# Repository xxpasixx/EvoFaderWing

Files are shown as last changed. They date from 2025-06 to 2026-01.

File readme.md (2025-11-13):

# EvoFaderWing - [Wiki](https://github.com/stagehandshawn/EvoFaderWing/wiki)

<table width="100%">
  <tr>
    <td width="70%">
      <table width="100%">
        <tr>
          <td align="left">
            <strong>Author:</strong> ShawnR
          </td>
          <td align="right">
            <strong>Contact:</strong> <a href="mailto:stagehandshawn@gmail.com">stagehandshawn@gmail.com</a>
          </td>
        </tr>
      </table>
      <br>
      OSC control of grandMA3 faders with motorized feedback, backlit faders (follows appearances), 20 encoders, and 40 standard exec buttons.
      <br><br><blockquote>
        <strong>Note:</strong> This Guide is a work in progress but EvoFaderWing is fully functional. I continue to work on the repo as time permits.
      </blockquote>
    </td>
    <td width="30%" align="right" valign="top">
      faderwing
    </td>
  </tr>
</table>

[Bill Of Materials](https://github.com/stagehandshawn/EvoFaderWing/wiki/Bill-of-materials)

[Wiring Diagrams](https://github.com/stagehandshawn/EvoFaderWing/wiki/Wiring-Diagrams)

[Assembly](https://github.com/stagehandshawn/EvoFaderWing/wiki/Assembly)

I have added discussions to the repo so any questions can be asked there. 

## Features
### Same quantity of control surfaces as grandMA3 onPC Fader Wing
- 10 Motorized faders
  - Touch sensitive
  - LED backlit - follows appearances and brightens when touched
  - Self calibrated fader range and touch sensitivity
- 40 Executor keys (OSC or USB)
   - Can send keystrokes using OSC to execute actions only
   - USB allows you to apply actions (store, edit, etc.) using the hardware keys
- 20 Executor Encoders
- Web GUI

## Project Images

<table>
  <tr>
    <td width="50%">
      faderwing top
    </td>
    <td width="50%">
      faderwing right side
    </td>
  </tr>
  <tr>
    <td width="50%">
      faderwing back
    </td>
    <td width="50%">
      electronics bay
    </td>
  </tr>
</table>

**Watch the demo videos**

⏺ <table>
    <tr>
      <td width="30%">
Watch the demo video (https://www.youtube.com/watch?v=cR3AajQKoAo)
      </td>
      <td width="30%">
Watch the demo video (https://www.youtube.com/watch?v=fbl81pGS5f4)
      </td>
      <td width="30%">
Watch the demo video (https://www.youtube.com/watch?v=7ICJlkqCzxY)
      </td>
    </tr>
  </table>

## Required repositories

There are 3 repositories you will need to complete this build. This one is the main controller. The other two are:

- **EvoFaderWing_keyboard_i2c**
- **EvoFaderWing_encoder_i2c**

These run on ATmega328p MCUs and are I2C slaves for getting encoder data from 20 encoders (5 each on 4 ATmega328p's), and 1 ATmega for the keyboard matrix.

There is a Python script and a `tasks.json` for uploading code automatically for when the FaderWing is closed and you cannot get to the bootloader button.

## Required Lua

The Lua script `/lua/EvoFaderWingOSC.lua` will poll executors and send updates to the FaderWing using bundled OSC messages, and the FaderWing will send OSC back to the script.

- You will need to create 2 OSC connections
  - The first will be for incoming messages and will be set to recieve.
  - The second will be from outgoing messages and will be set to send.
  - Both will need to be set to a fader range of 100

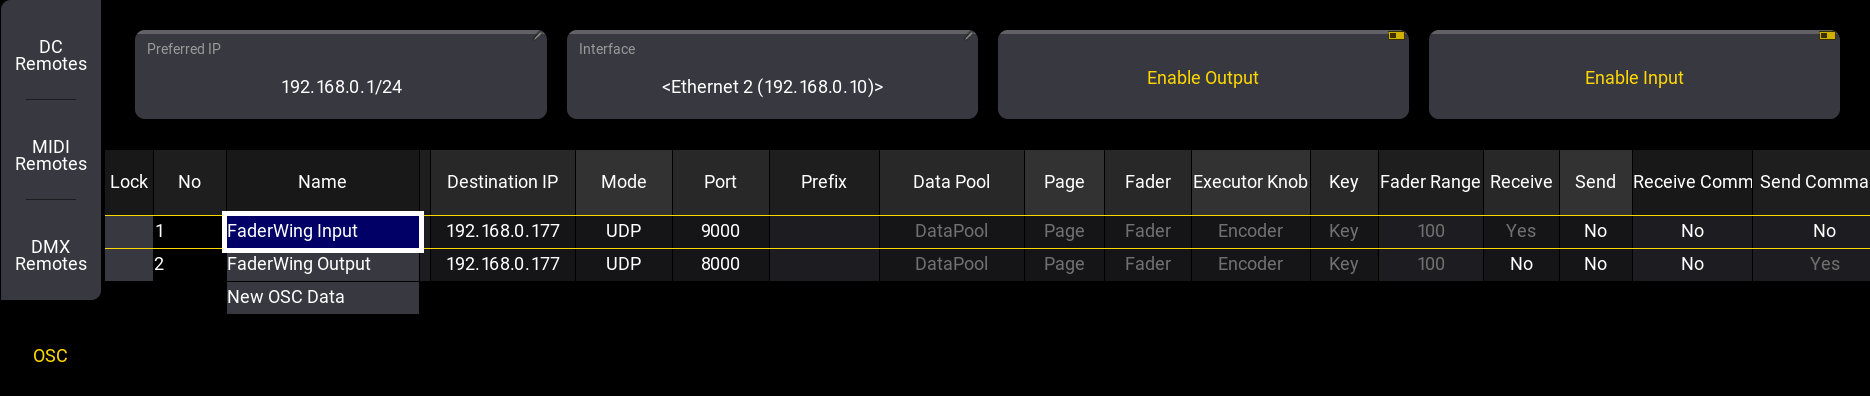
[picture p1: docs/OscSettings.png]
OscSettings


## Web GUI
- Network Setup

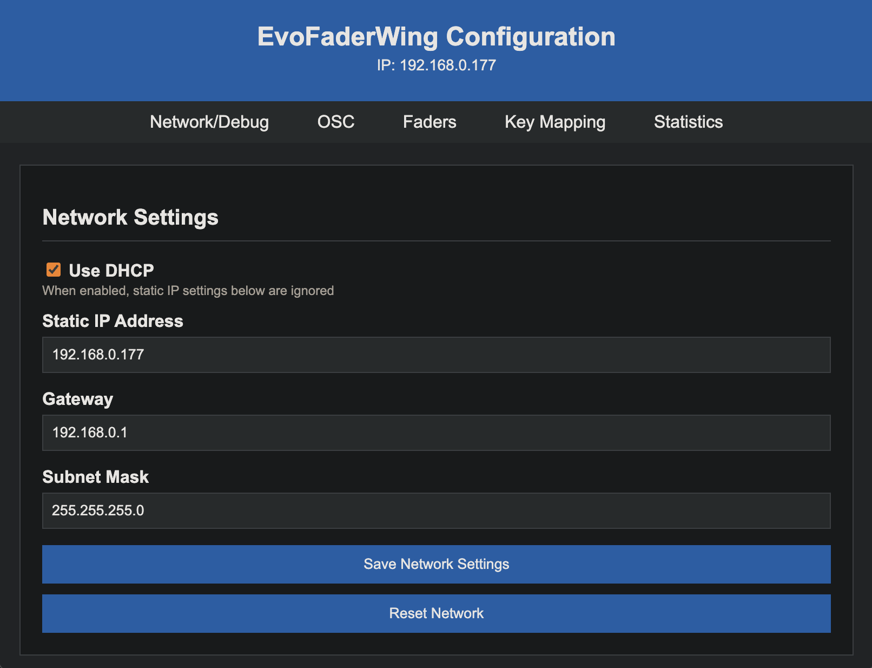
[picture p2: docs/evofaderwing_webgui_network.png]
NetowrkSetup


- OSC Setup

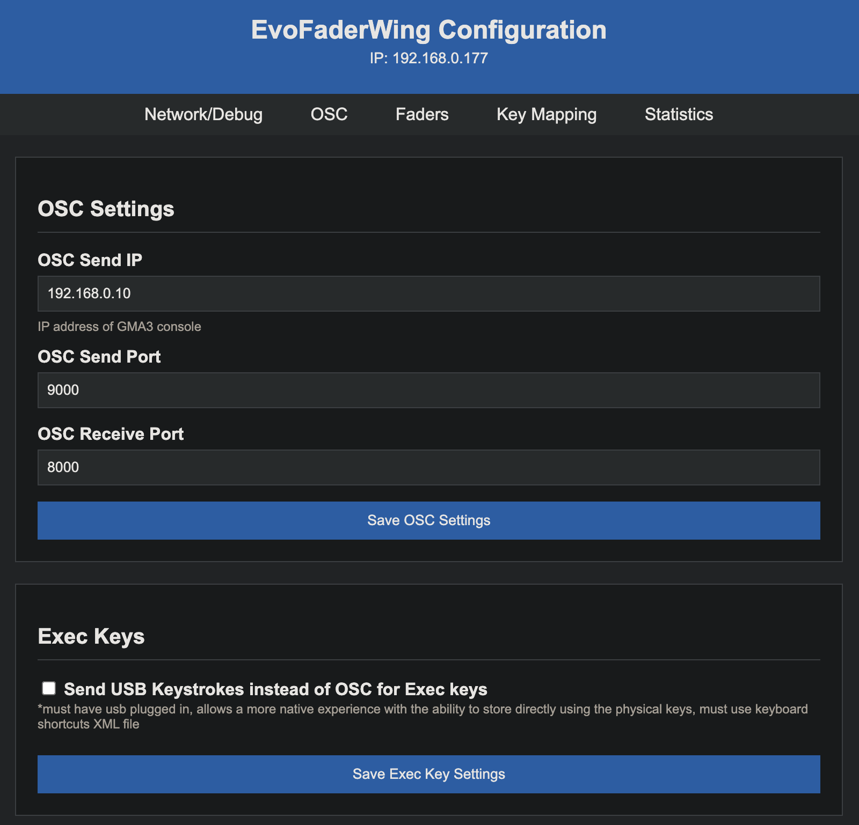
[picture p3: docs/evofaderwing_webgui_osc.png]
OscSetup


## For a complete setup add [EvoCmdWing](https://github.com/stagehandshawn/EvoCmdWing)
evocmdfaderwing

More to come. Thank you for checking out my project!

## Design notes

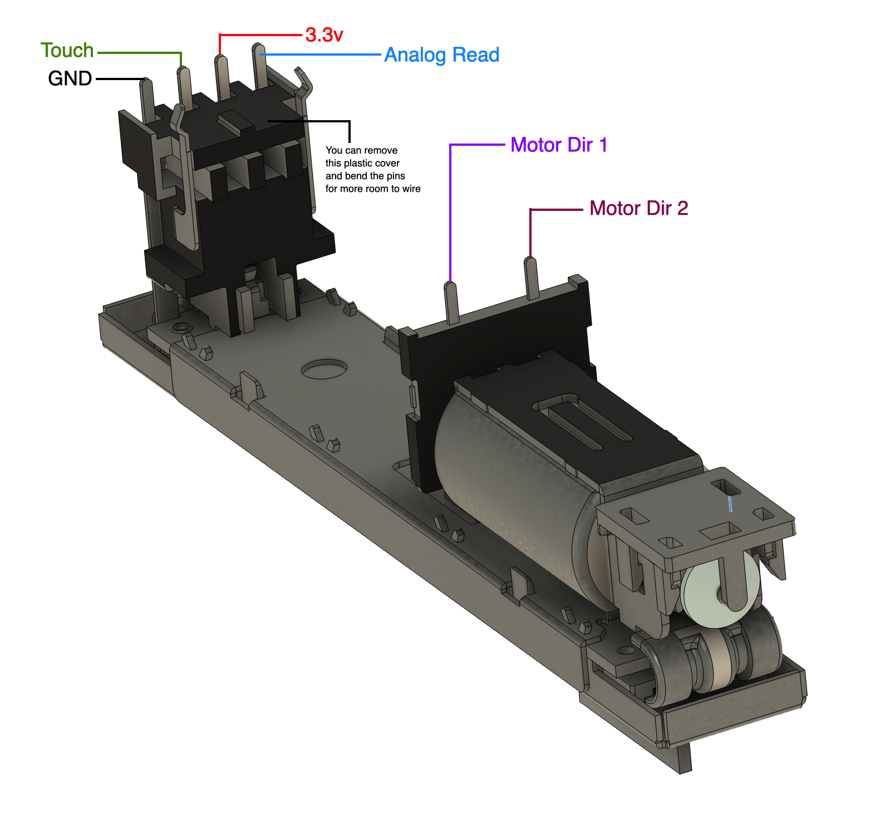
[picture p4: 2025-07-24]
docs/images/fader_MF60T_pinout.png

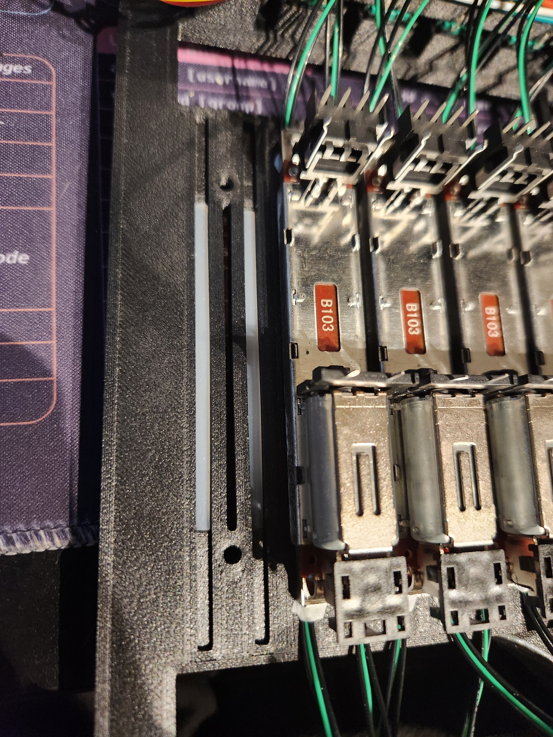
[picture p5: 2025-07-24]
docs/images/led_images/led_diffusion.jpg

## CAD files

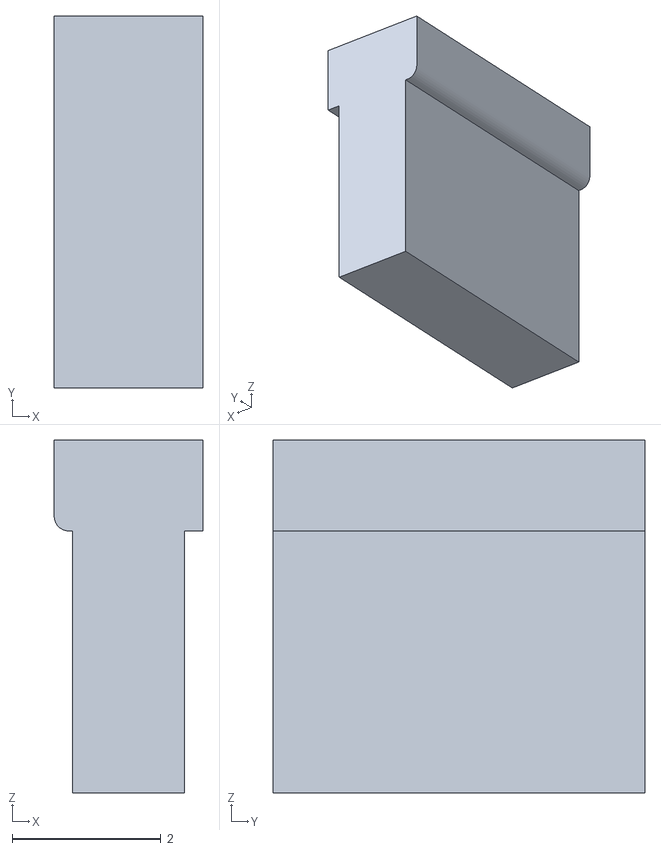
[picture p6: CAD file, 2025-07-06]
Cad_models/fader_insert_for_8mm.stl
2.00 x 5.00 x 4.74

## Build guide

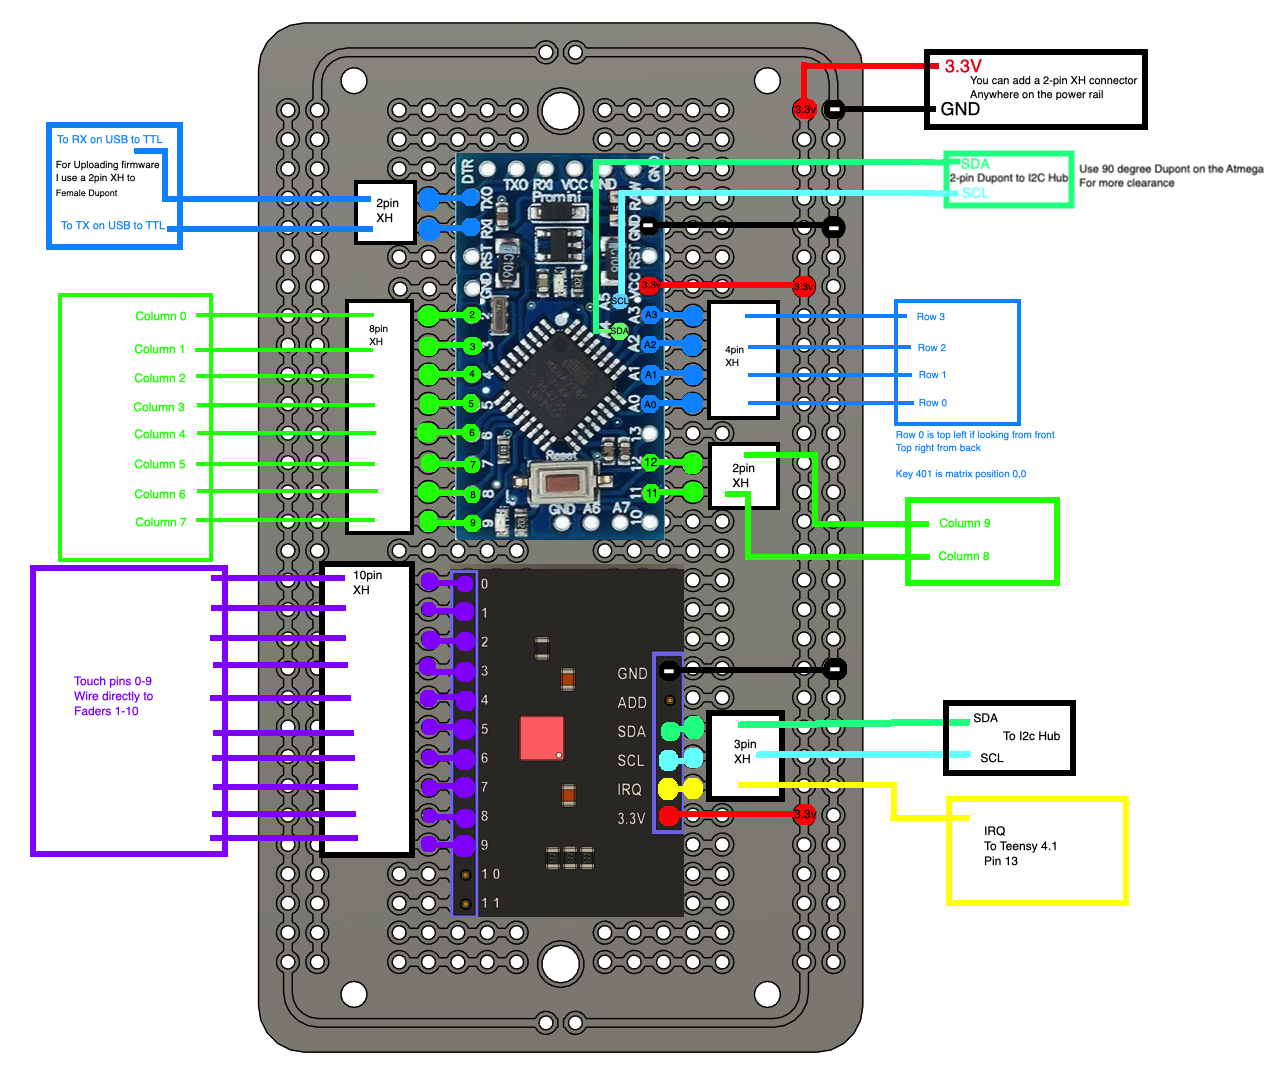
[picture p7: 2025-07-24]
docs/images/evofaderwing_keyboard_touch_wiring.png

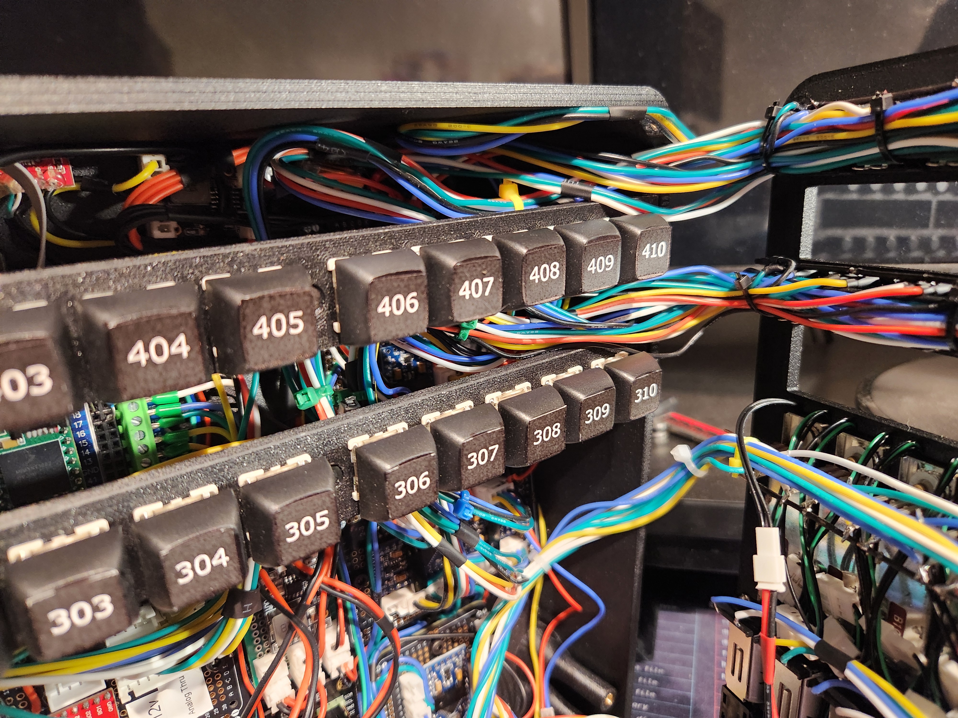
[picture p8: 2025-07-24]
docs/images/assembly/assembly_11.jpg

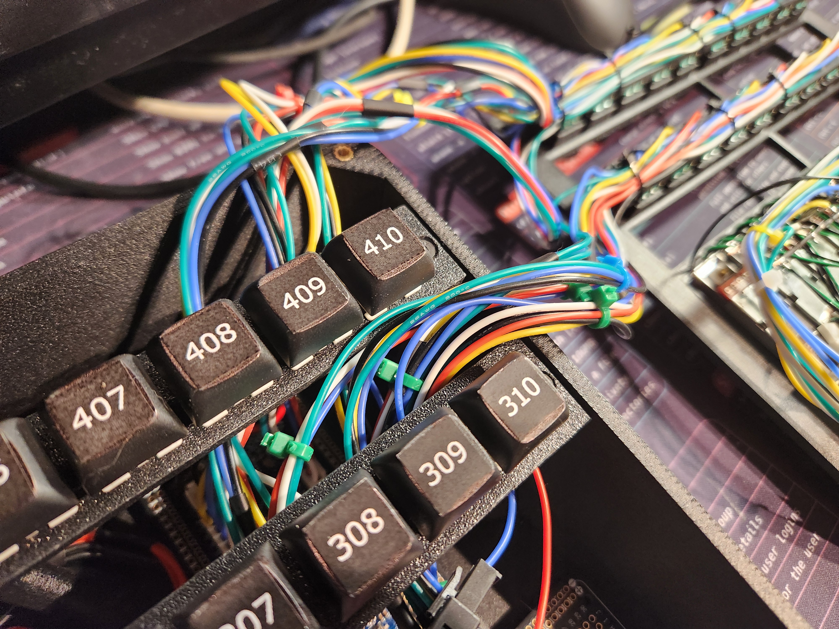
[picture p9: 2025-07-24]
docs/images/assembly/assembly_5.jpg

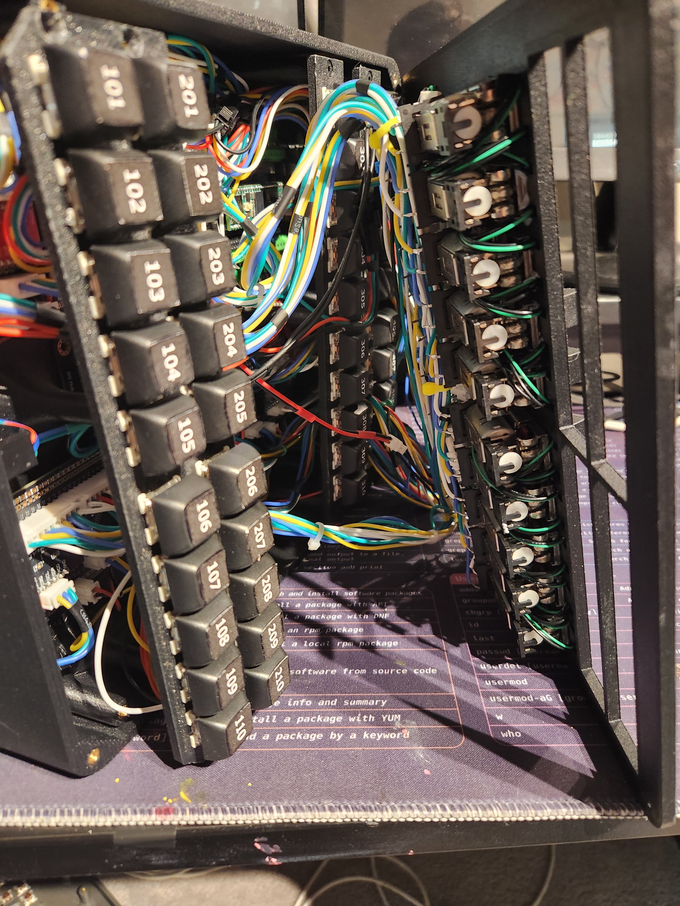
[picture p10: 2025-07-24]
docs/images/assembly/assembly_13.jpg

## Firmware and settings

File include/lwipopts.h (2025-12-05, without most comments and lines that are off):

#pragma once
#include "qnethernet/driver_select.h"
#include "qnethernet_opts.h"
#ifdef __cplusplus
extern "C" {
#endif  // __cplusplus
#define NO_SYS                 1
#define SYS_LIGHTWEIGHT_PROT          0
#define LWIP_ASSERT_CORE_LOCKED() \
  qnethernet_hal_check_core_locking(__FILE__, __LINE__, __func__)
void qnethernet_hal_check_core_locking(const char *file, int line,
                                       const char *func);
#define MEM_LIBC_MALLOC                        1
#define MEM_ALIGNMENT                          4
#define MEM_SIZE                               24000
#define MEMP_NUM_UDP_PCB                   8
#define MEMP_NUM_TCP_PCB                   8
#define MEMP_NUM_IGMP_GROUP                9
#define MEMP_NUM_SYS_TIMEOUT               ((LWIP_NUM_SYS_TIMEOUT_INTERNAL) + (8))
#define LWIP_ARP                      (LWIP_IPV4)
#define LWIP_ETHERNET                 1
#define LWIP_ICMP           (LWIP_IPV4)
#define LWIP_DHCP                       ((LWIP_IPV4) && (LWIP_UDP))
#define LWIP_DHCP_DOES_ACD_CHECK        0
#define LWIP_AUTOIP                 (LWIP_IPV4)
#define LWIP_DHCP_AUTOIP_COOP       ((LWIP_DHCP) && (LWIP_AUTOIP))
#define LWIP_IGMP LWIP_IPV4
#define LWIP_DNS                                (LWIP_UDP)
#define LWIP_DNS_SUPPORT_MDNS_QUERIES           1
#define LWIP_UDP             ((LWIP_IPV4) || (LWIP_IPV6))
#define LWIP_TCP                   ((LWIP_IPV4) || (LWIP_IPV6))
#define TCP_MSS                    ((MTU) - 40)
#define TCP_SND_BUF                (16 * (TCP_MSS))
#if LWIP_ALTCP && LWIP_ALTCP_TLS
#define TCP_WND                    (16 * 1024)
#else
#endif  // LWIP_ALTCP && LWIP_ALTCP_TLS
#define LWIP_SINGLE_NETIF              1
#define LWIP_NETIF_HOSTNAME            1
#define LWIP_NETIF_EXT_STATUS_CALLBACK 1
#define LWIP_NUM_NETIF_CLIENT_DATA     1
#define LWIP_NETCONN                0
#define LWIP_SOCKET                       0
#define SO_REUSE                          1
#define LWIP_STATS         0
#define LWIP_HOOK_FILENAME "qnethernet/lwip_hooks.h"
#define TFTP_MAX_FILENAME_LEN 512
#define SNTP_SERVER_DNS     1
#define SNTP_CHECK_RESPONSE 3
#define SNTP_UPDATE_DELAY   600000
#if defined(TEENSYDUINO) && defined(__IMXRT1062__)
#include <imxrt.h>
#include <sys/time.h>
#define SNTP_SET_SYSTEM_TIME_US(sec, us)                    \
  do {                                                      \
           \
    u32_t hi = (sec) >> 17;                                 \
    u32_t lo = ((sec) << 15) | ((us) << 9)/15625;           \
                                                            \
             \
             \
                                                            \
                                          \
    SNVS_HPCR &= ~(SNVS_HPCR_RTC_EN | SNVS_HPCR_HP_TS);     \
    while (SNVS_HPCR & SNVS_HPCR_RTC_EN) ;        \
                                         \
    SNVS_LPCR &= ~SNVS_LPCR_SRTC_ENV;                       \
    while (SNVS_LPCR & SNVS_LPCR_SRTC_ENV) ;      \
                                          \
    SNVS_LPSRTCLR = lo;                                     \
    SNVS_LPSRTCMR = hi;                                     \
                                        \
    SNVS_LPCR |= SNVS_LPCR_SRTC_ENV;                        \
    while (!(SNVS_LPCR & SNVS_LPCR_SRTC_ENV)) ;   \
                 \
    SNVS_HPCR |= SNVS_HPCR_RTC_EN | SNVS_HPCR_HP_TS;        \
  } while (0)
#define SNTP_GET_SYSTEM_TIME(sec, us) \
  do {                                \
    struct timeval tv;                \
    gettimeofday(&tv, NULL);          \
    (sec) = tv.tv_sec;                \
    (us) = tv.tv_usec;                \
  } while (0)
#endif  // defined(TEENSYDUINO) && defined(__IMXRT1062__)
#define LWIP_MDNS_RESPONDER (LWIP_UDP) && (LWIP_IGMP)
#define MDNS_MAX_SERVICES   3
#ifdef __cplusplus
}  // extern "C"
#endif  // __cplusplus

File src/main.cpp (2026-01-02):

// EvoFaderWing
// Main.cpp

// Teensy 4.1

#include <Arduino.h>
#include <QNEthernet.h>
#include <LiteOSCParser.h>

#include "Config.h"
#include "EEPROMStorage.h"
#include "TouchSensor.h"
#include "NetworkOSC.h"
#include "FaderControl.h"
#include "NeoPixelControl.h"
#include "WebServer.h"
#include "Utils.h"
#include "i2cPolling.h"
#include "OLED.h"
#include "Keysend.h"
#include "KeyLedControl.h"

using namespace qindesign::network;
using qindesign::osc::LiteOSCParser;


unsigned long lastI2CPollTime = 0;     // Time of last I2C poll cycle

OLED display;             // define display 
IPAddress currentIP;      // define currentIP

//================================
// MAIN ARDUINO FUNCTIONS
//================================

void setup() {
  // Start up keyboard first to make sure of enum in windows
  initKeyboard();

  Serial.begin(SERIAL_BAUD);
  while (!Serial && millis() < 4000) {}
  
  debugPrint("EvoFaderWing init...");

  // Initialize faders
  initializeFaders();
  configureFaderPins();
  
  // Initialize touch sensor (MTCH2120)
  if (!setupTouch()) {
    debugPrint("Touch sensor init failed!");
  }

  // Start NeoPixels
  setupNeoPixels();
  setupKeyLeds();

    // Check calibration will load calibration data if present ortherwise it will run calibration
  checkCalibration(); 

  // Load configurations from EEPROM
  loadAllConfig();

  moveAllFadersToSetpoints();
  // Calibrate touch sensor once faders are parked at center
  runTouchCalibration();

  //Setup I2C Slaves so we can also check for network reset
  setupI2cPolling();
  
  // Setup OLED before network to watch for no dhcp server and know were booting
  display.setupOLED();

  // Set up network connection
  setupNetwork();

  displayIPAddress();

  // Start web server for configuration
  startWebServer();

  fadeSequence(50,1000); // Cool effect so we know we are booted up

  //Network reset check
  resetCheckStartTime = millis();

  debugPrint("Initialization complete");

}

void loop() {
  // Network reset check exiry PRESS 401 5 times during this time for network reset

  if (checkForReset && (millis() - resetCheckStartTime > 5000)) {
    checkForReset = false;
    debugPrint("[RESET] Reset check window expired.");
  }
  
  checkFaderRetry();  // Check for hung fader

  // Check for manual fader movement
  handleFaders();

  // Handle I2C Polling for encoders keypresses and encoder key press
  handleI2c();

  // Process queued OSC packets from UDP callback
  processOscQueue();
  
    
  // Process touch changes 
  if (processTouchChanges()) { updateBrightnessOnFaderTouchChange(); }

  // Check for web requests
  pollWebServer();
  

  // Handle touch sensor errors, no longer needed used for debugging
  if (hasTouchError()) {
    debugPrint(getLastTouchError().c_str());
    clearTouchError();
  }
  
    // Update NeoPixels
  updateNeoPixels();
  updateKeyLeds();

  // Check for reboot from serial, used for uploading firmware without having to press physical button
  checkSerialForReboot();

}


// oled display functions

void displayIPAddress(){
  currentIP = Ethernet.localIP();
  display.showIPAddress(currentIP,netConfig.receivePort,netConfig.sendToIP,netConfig.sendPort);

}

void displayShowResetHeader(){
  display.clear();
  display.showHeader("Network Reset");
}

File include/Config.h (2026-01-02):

// Config.h
#ifndef CONFIG_H
#define CONFIG_H

#include <Arduino.h>
#include <IPAddress.h>

//================================
// IDENTITY
//================================
#define PROJECT_NAME "EvoFaderWing"
#define SW_VERSION      "0.3.1"

//================================
// HARDWARE CONFIGURATION
//================================

// Fader configuration
#define NUM_FADERS      10       // Total number of motorized faders
#define SERIAL_BAUD     115200   // Baud rate for USB serial output/debug

// Motor control settings THE PWM DEFAULTS ARE SET FOR A 12V PSU, is you use the correct 10v psu you will need to adjust them
#define MAX_PWM        150      // Default motor speed (PWM duty cycle) during normal operation (0–255) BEST at 100-150
#define CALIB_PWM       80       // Reduced motor speed during auto-calibration phase
#define MIN_PWM         40       // Minimum PWM to overcome motor inertia 
#define PWM_FREQ     25000      // Frequency of the motors PWM output 25khz
#define FADER_MOVE_TIMEOUT     2000   // Time in MS a fader must not be moving before force stopped
#define RETRY_INTERVAL         1000    // How long before trying to move a stuck fader
#define FADER_MAX_FAILURES       3     // Consecutive timeouts before disabling a fader motor

// Fader position tolerances
#define TARGET_TOLERANCE 1       // OSC VALUE How close the fader must be to setpoint to consider "done"
#define SEND_TOLERANCE   2       // Amout of change in OSC (0-100) before senind an osc update
#define ANALOG_NOISE_TOLERANCE 1 // Suppress tiny ADC jitter (counts) before mapping to OSC (current default set for 8bit reads)
#define SLOW_ZONE        25      // OSC units - start slowing earlier for smoother approach
#define FAST_ZONE        60      // OSC units - when to use full speed

// Calibration settings
#define PLATEAU_THRESH   2       // Threshold (analog delta) to consider that the fader has stopped moving
#define PLATEAU_COUNT    10      // How many stable readings in a row needed to "lock in" max or min during calibration


// OSC settings
#define OSC_VALUE_THRESHOLD 2    // Minimum value change to send OSC update
#define OSC_RATE_LIMIT     20    // Minimum ms between OSC messages

// NeoPixel configuration
#define NEOPIXEL_PIN 12
#define PIXELS_PER_FADER 24
#define NUM_PIXELS (NUM_FADERS * PIXELS_PER_FADER)

// Executor key NeoPixel strip (40 keys, 2 pixels each)
#define NUM_EXECUTORS_TRACKED 40
#define EXECUTOR_PIXELS_PER_KEY 2
#define EXECUTOR_LED_PIN 53   // Teensy 4.1 pin for the key strip
#define EXECUTOR_LED_COUNT (NUM_EXECUTORS_TRACKED * EXECUTOR_PIXELS_PER_KEY)
#define EXECUTOR_BASE_BRIGHTNESS 10   // Default base brightness for populated-but-off keys
#define EXECUTOR_ACTIVE_BRIGHTNESS 80 // Default brightness for active/on keys (unpopulated stays dark)

// Touch sensor configuration
#if defined(TOUCH_SENSOR_MTCH2120) && defined(TOUCH_SENSOR_MPR121)
#error "Select only one touch sensor: TOUCH_SENSOR_MTCH2120 or TOUCH_SENSOR_MPR121"
#endif

// Default to MTCH2120
#if !defined(TOUCH_SENSOR_MTCH2120) && !defined(TOUCH_SENSOR_MPR121)
#define TOUCH_SENSOR_MTCH2120 1
#endif

#define IRQ_PIN 13

#ifndef MTCH2120_ADDRESS
#define MTCH2120_ADDRESS 0x20
#endif

#ifndef MPR121_ADDRESS
#define MPR121_ADDRESS 0x5A
#endif

//================================
// PIN ASSIGNMENTS
//================================

// Analog input pins for fader position
extern const uint8_t ANALOG_PINS[NUM_FADERS];

// PWM output pins for motor speed
extern const uint8_t PWM_PINS[NUM_FADERS];

// Direction control pins for motors
extern const uint8_t DIR_PINS1[NUM_FADERS];
extern const uint8_t DIR_PINS2[NUM_FADERS];

// OSC IDs for each fader
extern const uint16_t OSC_IDS[NUM_FADERS];

//================================
// BRIGHTNESS SETTINGS
//================================


//================================
// NETWORK CONFIGURATION
//================================
constexpr uint32_t kDHCPTimeout = 15000;  // Timeout for DHCP in milliseconds
constexpr uint16_t kOSCPort = 8000;       // Default OSC port
constexpr char kServiceName[] = "evofaderwing"; // mDNS service name and Hostname

// Network configuration structure
struct NetworkConfig {
  IPAddress staticIP;     // Local static IP address
  IPAddress gateway;      // Default network gateway
  IPAddress subnet;       // Subnet mask
  IPAddress sendToIP;     // OSC destination IP address
  uint16_t  receivePort;  // OSC listening port (e.g. 8000)
  uint16_t  sendPort;     // OSC destination port (e.g. 9000)
  bool      useDHCP;      // If true, use DHCP instead of static IP
};

//================================
// FADER CONFIGURATION
//================================
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

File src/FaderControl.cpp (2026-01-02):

// FaderControl.cpp
#include "FaderControl.h"
#include "NetworkOSC.h"
#include "TouchSensor.h"
#include "WebServer.h"
#include "Utils.h"
#include "NeoPixelControl.h"


bool faderDebug = false;
bool FaderRetryPending = false;
unsigned long FaderRetryTime = 0;
static bool FaderMoveActive = false;

//================================
// MOTOR CONTROL
//================================


void driveMotorWithPWM(Fader& f, int direction, int pwmValue) {
  if (!f.motorEnabled) {
    // Keep motor off when disabled
    digitalWrite(f.dirPin1, LOW);
    digitalWrite(f.dirPin2, LOW);
    analogWrite(f.pwmPin, 0);
    return;
  }

  if (direction == 0) {
    // Stop the motor
    digitalWrite(f.dirPin1, LOW);
    digitalWrite(f.dirPin2, LOW);
    analogWrite(f.pwmPin, 0);
    return;
  }
  
  // Set direction pins
  if (direction > 0) {
    // Move up/forward
    digitalWrite(f.dirPin1, HIGH);
    digitalWrite(f.dirPin2, LOW);
  } else {
    // Move down/backward
    digitalWrite(f.dirPin1, LOW);
    digitalWrite(f.dirPin2, HIGH);
  }
  
  // Apply custom PWM speed
  analogWrite(f.pwmPin, pwmValue);
  
  if (faderDebug) {
    debugPrintf("Fader %d: Motor PWM: %d, Dir: %s, Setpoint: %d\n", 
               f.oscID, pwmValue, direction > 0 ? "UP" : "DOWN", f.setpoint);
  }
}

int calculateVelocityPWM(int difference) {
  int absDifference = abs(difference);
  
  // Define PWM ranges
  const int minPWM = Fconfig.minPwm;   // Minimum PWM to ensure movement (adjust as needed)
  const int maxPWM = Fconfig.maxPwm;  // Use your existing max PWM
  
  // Define distance thresholds for different speeds
  int slowZone = Fconfig.slowZone;   // OSC units - start slowing earlier for smoother approach
  int fastZone = Fconfig.fastZone;   // OSC units - when to use full speed
  // Guard against invalid values (OSC is 0-100)
  if (slowZone < 0) slowZone = 0;
  if (fastZone < 0) fastZone = 0;
  if (slowZone > 100) slowZone = 100;
  if (fastZone > 100) fastZone = 100;
  if (fastZone <= slowZone) {
    slowZone = SLOW_ZONE;
    fastZone = FAST_ZONE;
  }
  
  
  int pwmValue;
  
  if (absDifference >= fastZone) {
    // Far from target - use full speed
    pwmValue = maxPWM;
  } else if (absDifference <= slowZone) {
    // Close to target - use minimum speed
    pwmValue = minPWM;
  } else {
    // In between - linear interpolation
    float ratio = (float)(absDifference - slowZone) / (fastZone - slowZone);
    pwmValue = minPWM + (int)(ratio * (maxPWM - minPWM));
  }
  
  return pwmValue;
}


//================================
// MOVE ALL FADERs TO SETPOINT
//================================

void moveAllFadersToSetpoints() {
  if (FaderMoveActive) {
    // Already running; let the current pass finish using updated setpoints
    return;
  }
  FaderMoveActive = true;

  bool allFadersAtTarget = false;
  unsigned long moveStartTime = millis();

  while (!allFadersAtTarget) {
    allFadersAtTarget = true; // Assume all are at target until proven otherwise
    

    for (int i = 0; i < NUM_FADERS; i++) {
      Fader& f = faders[i];

      if (!f.motorEnabled) {
        // Disabled motors are treated as parked; ensure power is off
        driveMotorWithPWM(f, 0, 0);
        continue;
      }
      
      // Read current position as OSC value
      int currentOscValue = readFadertoOSC(f);
      
      
      // Calculate difference in OSC units
      int difference = f.setpoint - currentOscValue;
      
      // Check if we need to move this fader (using a smaller tolerance for OSC units) IF NOT TOUCHING IT
      if (abs(difference) > Fconfig.targetTolerance && !f.touched) {
        allFadersAtTarget = false; // At least one fader is not at target
        
        if (difference > 0) {
          // Need to move up
          int pwm = calculateVelocityPWM(difference);
          driveMotorWithPWM(f, 1, pwm);
        } else {
          // Need to move down  
          int pwm = calculateVelocityPWM(difference);
          driveMotorWithPWM(f, -1, pwm);
        }

        if (faderDebug) {
          debugPrintf("Fader %d: Current OSC: %d, Target OSC: %d, Diff: %d\n", 
                     f.oscID, currentOscValue, f.setpoint, difference);
        }

        } else {
          // Fader is at target, stop motor
          driveMotorWithPWM(f, 0, 0);
        }

    }
    
    // Yield to prevent overwhelming the system
    yield();
    
    // Add timeout protection to prevent infinite loops

    if (millis() - moveStartTime > FADER_MOVE_TIMEOUT) {
      // Stop all motors and flash red on faders that didn't reach target
      bool failed[NUM_FADERS] = {false};
      bool retryNeeded = false;
      uint8_t origColors[NUM_FADERS][3] = {{0}};
      uint8_t scaledRed = (uint8_t)((255UL * Fconfig.touchedBrightness) / 255UL);

      for (int i = 0; i < NUM_FADERS; i++) {
        Fader& f = faders[i];
        driveMotorWithPWM(f, 0, 0);

        if (!f.motorEnabled) {
          continue;
        }

        int currentOscValue = readFadertoOSC(f);
        int difference = f.setpoint - currentOscValue;
        if (abs(difference) > Fconfig.targetTolerance && !f.touched) {
          failed[i] = true;
          origColors[i][0] = f.red;
          origColors[i][1] = f.green;
          origColors[i][2] = f.blue;
        }
      }

      // Flash all failed faders together (full strip red) without using
      for (int flash = 0; flash < 3; flash++) {
        for (int i = 0; i < NUM_FADERS; i++) {
          if (!failed[i]) continue;
          for (int j = 0; j < PIXELS_PER_FADER; j++) {
            pixels.setPixelColor(i * PIXELS_PER_FADER + j, pixels.Color(scaledRed, 0, 0));
          }
        }
        pixels.show();
        delay(150);

        for (int i = 0; i < NUM_FADERS; i++) {
          if (!failed[i]) continue;
          for (int j = 0; j < PIXELS_PER_FADER; j++) {
            pixels.setPixelColor(i * PIXELS_PER_FADER + j, pixels.Color(origColors[i][0], origColors[i][1], origColors[i][2]));
          }
        }
        pixels.show();
        delay(50);
      }
      
      // Track failures and disable motors that repeatedly time out
      unsigned long failureTime = millis();
      for (int i = 0; i < NUM_FADERS; i++) {
        if (!failed[i]) {
          continue;
        }

        Fader& f = faders[i];
        f.failureCount++;
        f.lastFailureTime = failureTime;
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

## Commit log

2025-07-01 updated keyboard wiring diagram
2025-07-01 added send keystrokes to machine for use with shortcuts for better native control, not working on windows only mac for now
    [EEPROMStorage.h, OLED.cpp, i2cPolling.cpp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]
2025-07-03 added keysends.cpp and h to send keystrokes for exec buttons as an option
2025-07-03 added retry for faders not reaching setpoint, with led flash
2025-07-03 fixed network reset and add led feedback
    [EEPROMStorage.cpp, OLED.cpp, i2cPolling.cpp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]
2025-07-03 working on network reset without shutdown
    [Config.h, EEPROMStorage.cpp, FaderControl.cpp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]
2025-07-06 added model for an insert to fit fader knobs on 8mm post
    [fader_insert_for_8mm.stl]
2025-07-24 added assembly images
2025-07-24 added more assembly images
2025-11-28 added custom build for touch sensor refactor testing
2025-12-05 updated exec key led map to handle pixel gaps for easier installation of led strip
2025-12-08 Fixed: incorrect pin assignment for Neopixel line 2 (execkey leds) form 52 to 53)
    [Config.h]
2025-12-21 added: Support for MTCH2120 touch sensor define in platformio.ini, Fixed: Async UDP now uses ring buffer to offload work from ISR to main loop to keep from rare lockups from udp storms
    [Config.cpp, Config.h, TouchSensor.cpp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]
2025-12-21 Fixed: changed Pins 13 and 41 back to their original use (was changed for testing)
    [Config.cpp, Config.h]
2025-12-21 added: disable fader motor after failure, later will add color feedback and reload fader entry point, corrected pin assignments for use of MTCH2120 or MPR121, pins 13 and 41 swap depending on which s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
    [Config.cpp, Config.h, FaderControl.cpp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]
2025-12-21 Calibration of faders resets disabled faders
    [initFaders.cpp]
2025-12-28 Added dual touch sensor MPR121 or MTCH2120, more reliable, higher freq motor pwm, more reliable I2c, PIN CHANGE: IRQ pin 41, Fader DIR2 PIN is now 13
2026-01-02 feat: touch sensor offset

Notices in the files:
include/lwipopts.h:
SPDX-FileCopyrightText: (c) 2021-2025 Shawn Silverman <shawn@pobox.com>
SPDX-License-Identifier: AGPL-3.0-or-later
